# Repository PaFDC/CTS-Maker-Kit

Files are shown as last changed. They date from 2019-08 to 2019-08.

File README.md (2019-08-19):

# Knitted Capacitive Touch Sensor Maker Kit v1.0
This is a repository containing hardware and software source files and documentation for the Knitted Capacitive Touch Sensor (CTS) Maker Kit created by the [Pennsylvania Fabric Discovery Center](https://drexel.edu/functional-fabrics/initiatives/pennsylvania-fabric-discovery-center/).

## How to use this documentation
This documentation is a reference for the construction, application, and maintenance of the CTS hardware and software.

## Project contents
* __hardware__ - [Autodesk EAGLE](https://www.autodesk.com/products/eagle/overview) schematic (.sch) and board (.brd) files used to create the CTS PCB. This folder also contains a bill of materials (BOM) with descriptions of components.
* __firmware__ - Firmware flashed to the [PJRC Teensy 2.0](https://www.pjrc.com/store/teensy_pins.html) microcontroller included on the v1.0 maker kit sensing boards.
* __src__ - Source files for the CTS I2C library used to interface one or more sensor boards to an I2C-enabled Arduino-compatible microcontroller.
* __docs__ - Additional information related to hardware or software documentation.
* __apps__ - Demonstration applications created using the [Processing IDE](https://www.processing.org).

## Getting Started

### What's included in the Maker Kit?
The CTS Maker Kit v1.0 includes the following items:
* (1) Teensy 2.0 microcontroller
* (1) CTS PCB
* (1) Alligator to Molex connector
* (1) Knitted touchpad
* (1) USB type A to mini type B cable
* (1) Insert describing the CTS and containing a link to this GitHub project page.

### Connecting to a PC
The CTS connects to and is powered over USB. The device will mount as a USB serial port (e.g. `COM##` in Microsoft Windows, `/dev/cu.usbmodem#####` in Mac OSX, or `/dev/ttyUSB#` in Ubuntu Linux). You may use the Arduino IDE to monitor serial output by selecting `Tools > Serial Monitor`.

### Connecting to fabric
The alligator clips on the CTS module clip onto the button snaps affixed to the knitted touchpad. The clips can be removed from the PCB via the 3-pin, 0.1" pitch Molex connector. Users may create their own connectors to interface with the PCB using the following Molex [crimps](https://www.taydaelectronics.com/crimp-terminal-connector-3-96mm.html) and [housings](https://www.taydaelectronics.com/housing-connector-2-54mm-3-pins.html).

### Connecting with other CTS modules
The CTS contains breakouts for a 4-pin I2C connector. By default, each sensor board responds as a slave I2C device with address 0x01. The sensor boards can be connected individually to a host microcontroller or daisy-chained to report data from multiple toucpads. __Note:__ Version 1.0 CTS sensor boards must be re-flashed with a different I2C address to respond over the same bus.

The pinout of the I2C breakout is compatible with the [Sparkfun Qwiic I2C adapter](https://www.sparkfun.com/products/14495) with the exception that the voltage output of the sensor is __+5V__ and __not +3.3V__.

## Modifying the hardware
Schematic (.sch) and board layout (.brd) files are located in the __hardware__ folder.

### Extending the firmware
Further information can be found in the [ATmega 32U4 datasheet](http://ww1.microchip.com/downloads/en/devicedoc/atmel-7766-8-bit-avr-atmega16u4-32u4_datasheet.pdf).

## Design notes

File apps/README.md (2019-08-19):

# Knitted Capacitive Touch Sensor Maker Kit Applications

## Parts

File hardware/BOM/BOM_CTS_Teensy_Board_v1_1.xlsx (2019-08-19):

Part | Value | Device | Package | Description | PROD_ID | SF_ID | TP_SIGNAL_NAME | Vendor | Part Number | URL
D1 | RED | LED3MM | LED_3MM | LED (Generic) | DIO-08794 |  |  | Digikey | 732-5013-ND | https://www.digikey.com/product-detail/en/wurth-electronics-inc/151033RS03000/732-5013-ND/4490003
D2 | BLUE | LED3MM | LED_3MM | LED (Generic) | DIO-08794 |  |  | Digikey | 732-5011-ND | https://www.digikey.com/product-detail/en/wurth-electronics-inc/151033BS03000/732-5011-ND/4489997
J1 | 1x3 MOLEX KK-156 RIGHT ANGLE | CONN_03POLAR | MOLEX-1X3 | Multi connection point. Often used as Generic Header-pin footprint for 0.1 inch spaced/style header connections | CONN-08625 | PRT-08096 |  | Tayda Electronics | A-816 | https://www.taydaelectronics.com/wafer-connector-2-54mm-3-pins-right-angle.html
J2 | 1x12 FEMALE | CONN_12 | 1X12 | Multi connection point. Often used as Generic Header-pin footprint for 0.1 inch spaced/style header connections |  |  |  | Digikey | S7045-ND | https://www.digikey.com/product-detail/en/sullins-connector-solutions/PPPC121LFBN-RC/S7045-ND/810184
J3 | 1x12 FEMALE | CONN_12 | 1X12 | Multi connection point. Often used as Generic Header-pin footprint for 0.1 inch spaced/style header connections |  |  |  | Digikey | S7045-ND | https://www.digikey.com/product-detail/en/sullins-connector-solutions/PPPC121LFBN-RC/S7045-ND/810184
J4 | 1x4 MALE | CONN_04 | 1X04 | Multi connection point. Often used as Generic Header-pin footprint for 0.1 inch spaced/style header connections | CONN-09696 |  |  | Digikey | S1112EC-02-ND | https://www.digikey.com/product-detail/en/sullins-connector-solutions/PREC002SBAN-M71RC/S1112EC-02-ND/2774932
J5 | 1x4 MALE | CONN_04 | 1X04 | Multi connection point. Often used as Generic Header-pin footprint for 0.1 inch spaced/style header connections | CONN-09696 |  |  | Digikey | S1112EC-02-ND | https://www.digikey.com/product-detail/en/sullins-connector-solutions/PREC002SBAN-M71RC/S1112EC-02-ND/2774932
R1 | 150 | R-US_0204/7 | 0204/7 | RESISTOR, American symbol |  |  |  | Digikey | S150CACT-ND | https://www.digikey.com/product-detail/en/stackpole-electronics-inc/RNMF14FTC150R/S150CACT-ND/2617812
R2 | 100 | R-US_0204/7 | 0204/7 | RESISTOR, American symbol |  |  |  | Digikey | S100CACT-ND | https://www.digikey.com/products/en?keywords=S100CACT-ND
R3 | 1M | TRIM_US-B90P | SP19L | POTENTIOMETER |  |  |  | Digikey | 3006P-105LF-ND | https://www.digikey.com/product-detail/en/bourns-inc/3006P-1-105LF/3006P-105LF-ND/1087573
R4 | 1M | TRIM_US-B90P | SP19L | POTENTIOMETER |  |  |  | Digikey | 3006P-105LF-ND | https://www.digikey.com/product-detail/en/bourns-inc/3006P-1-105LF/3006P-105LF-ND/1087573
R5 | 4.7K | R-US_0204/7 | 0204/7 | RESISTOR, American symbol |  |  |  | Digikey | S4.7KCACT-ND | https://www.digikey.com/product-detail/en/stackpole-electronics-inc/RNMF14FTC4K70/S4.7KCACT-ND/2617510
R6 | 4.7K | R-US_0204/7 | 0204/7 | RESISTOR, American symbol |  |  |  | Digikey | S4.7KCACT-ND | https://www.digikey.com/product-detail/en/stackpole-electronics-inc/RNMF14FTC4K70/S4.7KCACT-ND/2617510

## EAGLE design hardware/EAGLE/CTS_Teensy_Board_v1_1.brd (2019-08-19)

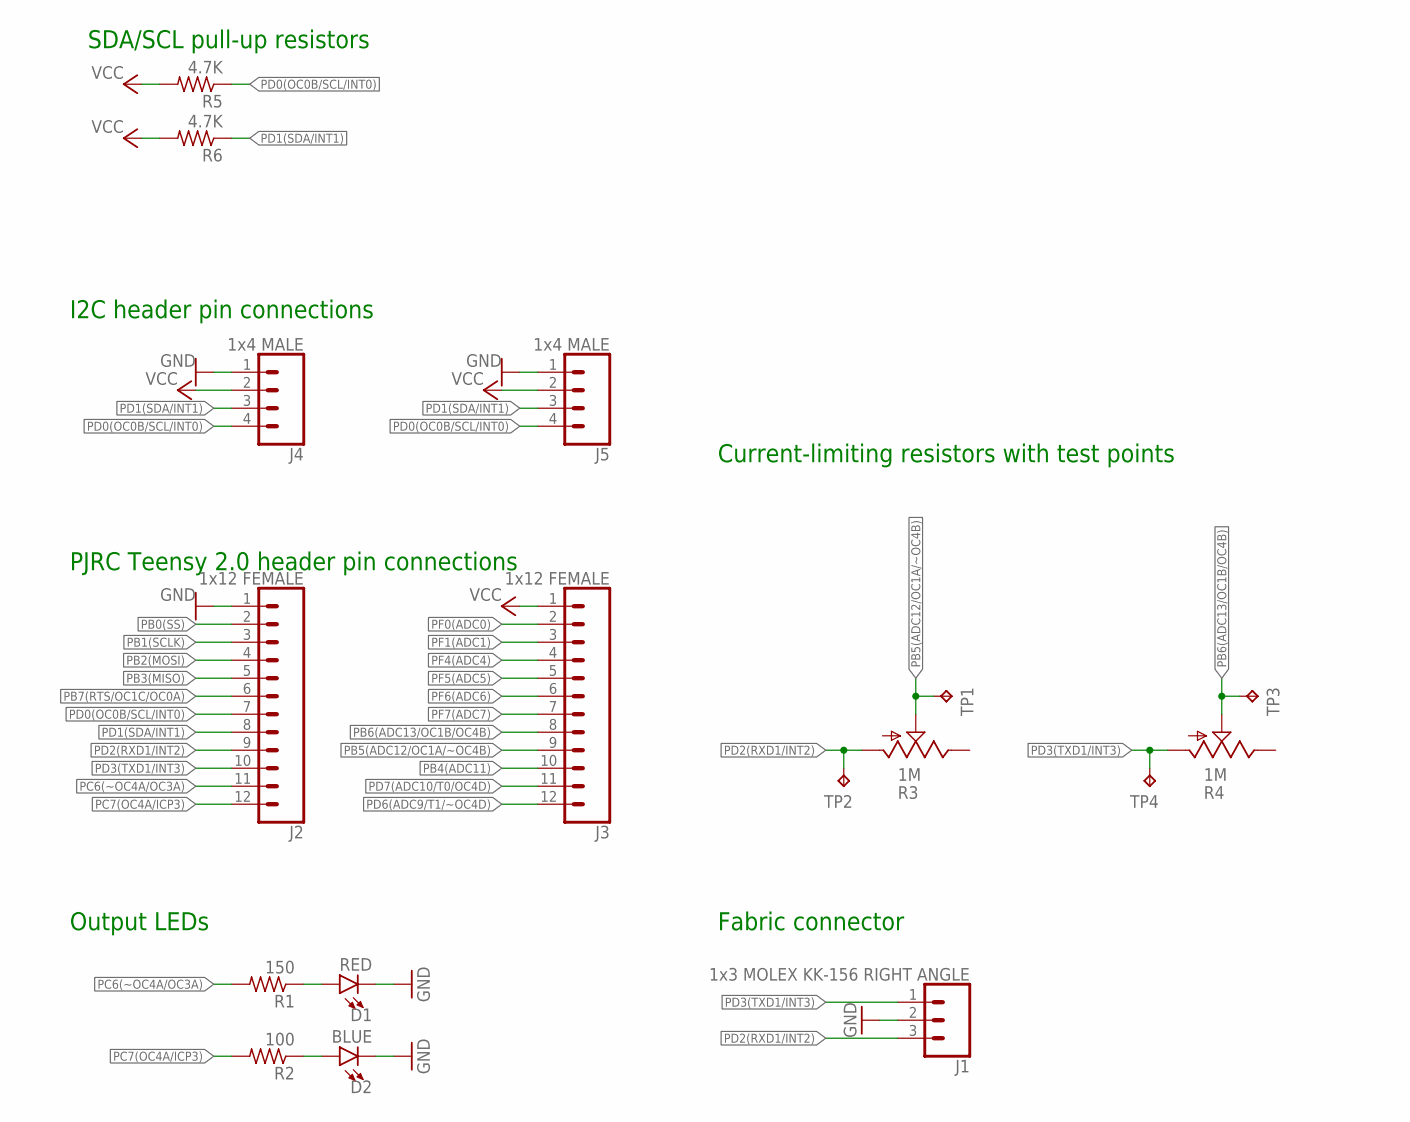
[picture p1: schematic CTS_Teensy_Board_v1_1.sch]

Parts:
D1: RED; LED_3MM
D2: BLUE; LED_3MM
J1: 1x3 MOLEX KK-156 RIGHT ANGLE; MOLEX-1X3
J2, J3: 1x12 FEMALE; 1X12
J4, J5: 1x4 MALE; 1X04
R1: 150; 0204/7
R2: 100; 0204/7
R3, R4: 1M; SP19L
R5, R6: 4.7K; 0204/7
TP1, TP2, TP3, TP4: TPTP18R; TP18R

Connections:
GND: D1.K (C), D2.K (C), J1.2, J2.1, J4.1, J5.1
unnamed: D2.A, R2.1
unnamed: D1.A, R1.1
PB0(SS): J2.2
PB1(SCLK): J2.3
PB2(MOSI): J2.4
PB3(MISO): J2.5
PB4(ADC11): J3.10
PB5(ADC12/OC1A/~OC4B): J3.9, R3.S, TP1.TP
PB6(ADC13/OC1B/OC4B): J3.8, R4.S, TP3.TP
PB7(RTS/OC1C/OC0A): J2.6
PC6(~OC4A/OC3A): J2.11, R1.2
PC7(OC4A/ICP3): J2.12, R2.2
PD0(OC0B/SCL/INT0): J2.7, J4.4, J5.4, R5.1
PD1(SDA/INT1): J2.8, J4.3, J5.3, R6.1
PD2(RXD1/INT2): J1.3, J2.9, R3.A, TP2.TP
PD3(TXD1/INT3): J1.1, J2.10, R4.A, TP4.TP
PD6(ADC9/T1/~OC4D): J3.12
PD7(ADC10/T0/OC4D): J3.11
PF0(ADC0): J3.2
PF1(ADC1): J3.3
PF4(ADC4): J3.4
PF5(ADC5): J3.5
PF6(ADC6): J3.6
PF7(ADC7): J3.7
VCC: J3.1, J4.2, J5.2, R5.2, R6.2

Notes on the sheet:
SDA/SCL pull-up resistors
I2C header pin connections
PJRC Teensy 2.0 header pin connections
Current-limiting resistors with test points
Output LEDs
Fabric connector

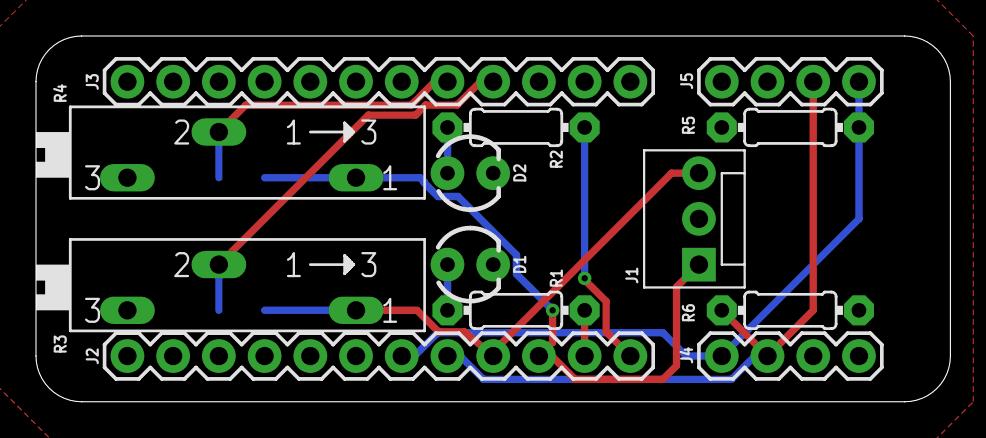
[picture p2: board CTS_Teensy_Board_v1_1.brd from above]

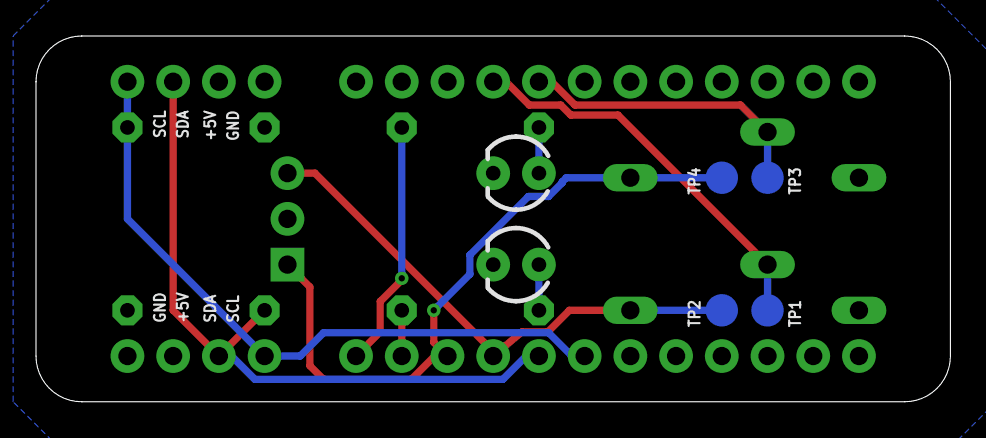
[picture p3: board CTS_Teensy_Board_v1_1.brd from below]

Board: 2 copper layers, 50.8 x 20.3 mm, 17 parts (4 on the bottom side), 12 nets.

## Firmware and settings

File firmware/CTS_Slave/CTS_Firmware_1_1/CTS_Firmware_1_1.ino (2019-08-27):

/*
 *                Teensy 2.0 (Atmega 32U4)
 *                        _______
 *                    ___|       |___
 *               Gnd | o |       | o | Vcc
 * (interior) SS PB0 | o |_______| o | PF0 ADC0       (interior)
 *  PE6     SCLK PB1 | o           o | PF1 ADC1          AREF
 *  AIN0    MOSI PB2 | o           o | PF4 ADC4
 *  INT6    MISO PB3 | o o       o o | PF5 ADC5
 * RTS OC1C OC0A PB7 | o   _____   o | PF6 ADC6
 * OC0B SCL INT0 PD0 | o  |     |  o | PF7 ADC7
 *      SDA INT1 PD1 | o  |     |  o | PB6 ADC13 OC1B OC4B
 *     RXD1 INT2 PD2 | o  |_____|  o | PB5 ADC12 OC1A OC4B
 *     TXD1 INT3 PD3 | o           o | PB4 ADC11
 *    !OC4A OC3A PC6 | o    [   ]  o | PD7 ADC10 T0 OC4D
 *     OC4A ICP3 PC7 | o o o o o o o | PD6 ADC9  T1 !OC4D (LED on PD6)
 *                   |___|_|_|_|_|___|
 *                       | | | | |
 *            CTS XCK1 PD5 | | | PD4 ADC8 ICP1
 *                       Vcc | RST
 *                          GND
 * 
 *                        _______
 *                    ___|       |___
 *               Gnd | o |       | o | Vcc
 * (interior)      0 | o |_______| o | 21 A0        (interior)
 *     24          1 | o           o | 20 A1           AREF
 *                 2 | o           o | 19 A2
 *                 3 | o o       o o | 18 A3
 *        PWM      4 | o   _____   o | 17 A4
 *        PWM INT0 5 | o  |     |  o | 16 A5
 *            INT1 6 | o  |     |  o | 15 A6  PWM
 *         RX INT2 7 | o  |_____|  o | 14 A7  PWM
 *         TX INT3 8 | o           o | 13 A8
 *        PWM      9 | o    [   ]  o | 12 A9  PWM
 *        PWM     10 | o o o o o o o | 11 A10 (LED on 11)
 *                   |___|_|_|_|_|___|
 *                       | | | | |
 *                      23 | | | 22, A11
 *                       Vcc | RST
 *                          GND
 */


/*
 *  Clock Divisor Table
 * 0 | 0 | 0 No clock source
 * 0 | 0 | 1 clk/1
 * 0 | 1 | 0 clk/8
 * 0 | 1 | 1 clk/64
 * 1 | 0 | 0 clk/256
 * 1 | 0 | 1 clk/1024
 * 1 | 1 | 0 
 * 1 | 1 | 1 
 * 
 */


/*
 * Cyclical Buffer Operation
 * 
 * We define a buffer with n elements numbered from 0 to n-1.
 * The buffer elements contain readings taken sequentially.
 * We define an index to track which element is being written/overwritten.
 * We also define a buffer sum that keeps track of the sum of all elements within the buffer.
 * When a reading is taken, the value is placed in an element and the write index is incremented.
 * The removed element is subtracted from the buffer sum and the reading is added.
 * When the index reaches the end of the buffer, the index wraps around to zero.
 * 
 *      buffer, index = x          (n-4) (n-2)
 *  0  1  2  3  4  5  6     x   (n-5) (n-3) (n-1)
 * [#][#][#][#][#][#][#]...[#]...[#][#][#][#][#]
 * 
 * 
 * buffer_sum = buffer_sum + reading
 * buffer_sum = buffer_sum - buffer[x]
 * buffer[x] = reading;
 * 
 * Caveats:
 * 1. Alays add to the buffer sum before subtracting, especially if the buffer sum is an unsigned quantity.
 * 2. Avoid adding and subtracting quantities in the same line to avoid order of operations conflicts and variable wrap-around.
 * 
 */


/*
 * Exponential Moving Average
 * 
 * S_t = Y_1,               t = 1
 *       a*Y_t + (1-a)*S_t, t > 1
 * 
 * a ~= 0: Favor prior readings over newer readings
 * a ~= 1: Favor newer readings over prior readings
 * 
 */

#include <Wire.h>
#include <EEPROM.h>
#include "cts_utility.h"

// Length of the cyclical buffer used for the low-pass filter reading
// Higher values produce a "smoother" output but slow responsiveness to changes in touch
#define CYC_BUFF_LEN (128)

#define MHz_TO_MICROS (16)    // Scaling clock ticks in MHz to microseconds
#define DT_TO_DELAY   (1000)  // 1000 Microseconds per 1 Hz
#define SAMPLE_RATE   (100)   // Hz, approximate
#define CUTOFF        (5)     // Hz

// A (red) and B (blue) electrode LED pins
#define REDLED (10)           // Pin 10
#define BLUELED (9)           // Pin 9

#define CYC_BASELINE_BUFF_LEN (128) // 


#define EEPROM_I2C_ADDRESS (0)


// I2C slave address
uint8_t address = 1;

volatile uint8_t state = 0;     // State of timer interrupt (intital condition)

uint8_t idx = 0;                // Index of the cyclical buffer
uint32_t buffer_overflow = 0;   // Number of times the cyclical buffer has overflowed

// Wait "n" number of milliseconds to begin analyzing readings
// This gives the buffer time to flush dummy (zero) readings and populate with real data
uint16_t start_after = 2000;

uint16_t cyc_buffer[CYC_BUFF_LEN][2] = { { 0, }, { 0, } }; // Definition of the cyclical buffer
uint32_t cyc_buffer_sum[2] = { 0, }; // Definition of the buffer sum

uint16_t tau_A = 0; // Signal A rise time
uint16_t tau_B = 0; // Signal B rise time

float smoothreadings[2][2] = { { 0, 0 }, { 0, 0 } };
float highpass[2][2] = { { 0, 0 }, { 0, 0 } };

// Filter gains
float dt = 1.0/SAMPLE_RATE;     // Time change
float RC = 1.0/(2.0*PI*CUTOFF); // "RC" constant of system
float alpha = RC/(RC + dt);     // High pass filter gain

// A and B electrode signal reading
float sigA = 0.0;
float sigB = 0.0;

float sigAScaled = 1.0;
float sigBScaled = 1.0;

uint8_t ledA = 0;
uint8_t ledB = 0;

float minReading[] = { 1000.0, 1000.0 };
float maxReading[] = { 0.0, 0.0 };

uint8_t minLEDBrightness[] = { 0, 0 };
uint8_t maxLEDBrightness[] = { 63, 63 };

uint32_t delay_time = (uint32_t)(DT_TO_DELAY*dt);

// Empirically observed base rise time
float baseA = 18.0;
float baseB = 18.0;

float th = 0.30;

uint8_t istouched  = 0;

String delim = " ";

float pressThreshold = 10.0;
float releaseThreshold = -2.5;

float valuemin = -1.0;
float valuemax = 0.9;
float outmin = 0.0;
float outmax = 25.0;

int channel = 1;
uint8_t note = 48;
uint8_t velocity = 99;

float baseline[CYC_BASELINE_BUFF_LEN][2] = { { 0.0 }, { 0.0 } };
float baseline_sum[2] = { 0, 0 };
uint8_t baseline_idx = 0;

struct CTSDataStruct{
  float raw[2];
  float highpass[2];
  float x;
  float pressure;
} dataStruct;

void setup() {
  // Start the serial port
  Serial.begin(115200);

  // Start the I2C port with the specified address
  Wire.begin(address);

  // Set the I2C request for data callback function
  Wire.onRequest(wireCallback);

  // Enable the built-in LED
  pinMode(LED_BUILTIN, OUTPUT);

  // Set the PWM-enabled LED pins
  pinMode(REDLED, ledA);
  pinMode(BLUELED, ledB);

  // Initialize the CTS pins
  initCTS();

  // Wait for serial connection
  //while (!Serial);
  delay(start_after);

  // Turn on the built-in LED
  digitalWrite(LED_BUILTIN, HIGH);
}

/*
 * TODO:
 * self-calibration
 * 
 * The sensor subtracts an offset reading from the A and B signals when there is no touch.
 * The sensor is allowed to adjust the baseline offset when
 * 
 * Map the exponential filter alpha between 0 and 1
 * 
 */

void loop() {
  // Delay the loop
  delay(delay_time);
  
  // Get the windowed moving average
  sigA = (float)cyc_buffer_sum[0]/(MHz_TO_MICROS*CYC_BUFF_LEN);
  sigB = (float)cyc_buffer_sum[1]/(MHz_TO_MICROS*CYC_BUFF_LEN);
  
  // Set the average to the smoothing window
  smoothreadings[0][0] = sigA;
  smoothreadings[1][0] = sigB;
  
  // Find the highpass filter value
  highpass[0][0] = alpha*(highpass[0][1] + smoothreadings[0][0] - smoothreadings[0][1]);
  highpass[1][0] = alpha*(highpass[1][1] + smoothreadings[1][0] - smoothreadings[1][1]);

  
  if ((abs(highpass[0][0]) > th || abs(highpass[1][0]) > th) && !istouched) {
    Serial.println("Here");
    istouched = true;  // Raise touched flag
    digitalWrite(LED_BUILTIN, LOW);
    baseA = baseline_sum[0]/CYC_BASELINE_BUFF_LEN;
    baseB = baseline_sum[1]/CYC_BASELINE_BUFF_LEN;
  } else if (!istouched) {
    baseline_sum[0] += sigA;
    baseline_sum[1] += sigB;
    baseline_sum[0] -= baseline[baseline_idx][0];
    baseline_sum[1] -= baseline[baseline_idx][1];
    baseline[baseline_idx][0] = sigA;
    baseline[baseline_idx][1] = sigB;
    digitalWrite(LED_BUILTIN, LOW);
    baseline_idx++;
    baseline_idx = (baseline_idx >= CYC_BASELINE_BUFF_LEN)? 0 : baseline_idx;
  } else if ((abs(highpass[0][0]) < th || abs(highpass[1][0]) < th) && istouched) {
    istouched = false;  // Lower touched flag
    digitalWrite(LED_BUILTIN, LOW);
  }
  
  // 
  sigAScaled = sigA - baseA;
  sigBScaled = sigB - baseB;
  
  // 
  sigAScaled = (sigAScaled < 1.0)? 1.0 : sigAScaled;
  sigBScaled = (sigBScaled < 1.0)? 1.0 : sigBScaled;
  
  // 
  ledA = (uint8_t)map(sigAScaled, 1.0, 60.0, 0, 127);
  ledB = (uint8_t)map(sigBScaled, 1.0, 60.0, 0, 127);
  
  //updateReadingLimits();
  
  // 
  highpass[0][1] = highpass[0][0];
  highpass[1][1] = highpass[1][0];
  smoothreadings[0][1] = smoothreadings[0][0];
  smoothreadings[1][1] = smoothreadings[1][0];
  
  // 
  analogWrite(REDLED, ledA);
  analogWrite(BLUELED, ledB);
  

  dataStruct.raw[0] = sigA;
  dataStruct.raw[1] = sigB;
  dataStruct.highpass[0] = highpass[0][0];
  dataStruct.highpass[1] = highpass[1][0];
  dataStruct.x = log(sigAScaled) - log(sigBScaled);
  dataStruct.pressure = (sigAScaled + sigBScaled)/2.0 - 1.0;

  Serial.print(dataStruct.raw[0]);
  Serial.print(delim);
  Serial.print(dataStruct.raw[1]);
  Serial.print(delim);
  Serial.print(dataStruct.highpass[0]);
  Serial.print(delim);
  Serial.print(dataStruct.highpass[1]);
  Serial.print(delim);
  Serial.print(dataStruct.x);
  Serial.print(delim);
  Serial.println(dataStruct.pressure);
  
  delay(10);
}

void wireCallback() {
  Wire.write((uint8_t *)&dataStruct, 24);
}




void updateReadingLimits() {    
  //ledA = map(sigA, minReading[0], maxReading[0], 0.0, 1.0);
  //if ledA < 0
  //ledB = map(sigB, minReading[1], maxReading[1], 0.0, 1.0);
}

/*
 * External Interrupt INT0 (Digital pin 5)
 */
ISR(INT2_vect) {
  tau_A = TCNT1;        // Record the signal A rise time
  PORTD |= (1 << DDD5); // Fire the interrupt trigger
}

/*
 * External Interrupt INT1 (Digital pin 6)
 */
ISR(INT3_vect) {
  tau_B = TCNT1;        // Record the signal B rise time
  PORTD |= (1 << DDD6); // Fire the interrupt trigger
}

/*
 * TIMER1 Compare channel A vector
 */
ISR(TIMER1_COMPA_vect) {
  // Invert digital pins 9 and 10
  PORTB ^= (1 << DDB6) | (1 << DDB5);

  // Put the tau_A and tau_B readings into the cyclical buffer (add before subtracting)
  cyc_buffer_sum[0] += tau_A;
  cyc_buffer_sum[0] -= cyc_buffer[idx][0];
  cyc_buffer_sum[1] += tau_B;
  cyc_buffer_sum[1] -= cyc_buffer[idx][1];
  cyc_buffer[idx][0] = tau_A;
  cyc_buffer[idx][1] = tau_B;

  idx++; // Increment the buffer index and reset to zero if it reaches the end
  if (idx >= CYC_BUFF_LEN) {
    idx = 0;
    buffer_overflow++;
  }
}

/*
 * TIMER1 Compare channel B vector
 */
ISR(TIMER1_COMPB_vect) {
  // Do nothing
}

uint8_t readAddress() {
  return EEPROM.read(EEPROM_I2C_ADDRESS);
}

/*Serial.print(dataStruct.raw[0]);
  Serial.print(delim);
  Serial.print(dataStruct.raw[1]);
  Serial.print(delim);
  Serial.print(dataStruct.highpass[0]);
  Serial.print(delim);
  Serial.print(dataStruct.highpass[1]);
  Serial.print(delim);
  Serial.print(dataStruct.x);
  Serial.print(delim);
  Serial.print(dataStruct.pressure);
  Serial.print(delim);
  Serial.print(baseline_sum[0]);
  Serial.print(delim);
  Serial.print(baseline_sum[1]);
  Serial.print(delim);
  */

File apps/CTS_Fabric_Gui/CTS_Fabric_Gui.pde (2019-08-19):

import processing.serial.*;
import javax.swing.*; //for serial port prompt

boolean setup = true;
// toggle prompt for choosing serial port

int lf = 10;  // linefeed in ASCII
String myString = null; //raw serial data
float[] data = new float[2]; //serial data split in 2 numbers
Serial myPort;  // serial port

float margin, headerHeight, rectsHeight, barsHeight, graphHeight;

int rgb[][] = {
  { 200, 55, 110 }, //0: left axis
  {  20, 85, 140 }
}; //1: right axis
color bg = color(242);
color light = color(245, 195, 215); //light pressure
color dark = color(200, 55, 110); //heavy pressure 
color header = color(255); //header text
color stroke = color(190);
color subtitleBG = color(20, 85, 140);
color subtitle = color(255);
color rectsFill = color(230, 245, 255);

int numRects = 16; // number of sensor rectangles
int maxRects = 40; // max number of sensor rectangles
int rectInc = 2; // sensitivity increment
float[][] rects = new float[maxRects][4]; // coordinates for each rect


float[][] readings = new float[4][2000]; // all readings
// 0: left readings
// 1: right readings
// 2: raw n value
// 3: n-normalized

float[][] plot = new float[2][2000]; // scaled left-right readings

float time[] = new float[2000];
float startingLine = 0.9; // how far across the screen the current data point is drawn

volatile int vIdx = 1300;
int idx = 1300;

volatile boolean vRunning = true;
boolean running = true;
boolean console = false;
boolean mousePause = false;
boolean mouseReset = false;
boolean mouseConsole = false;

float sensitivity[][] = { { 10.0, 40.0 }, { 20.0, 40.0 }, { 15.0, 20.0 }, {10.0, 15.0 } };
int sidx = 0; // Sensitivity index
float pLower = sensitivity[sidx][0]; // Default to first lower pressure sensitivity
float pUpper = sensitivity[sidx][1]; // Default to first upper pressure sensitivity

int inc = 30; // arrow increment

PImage logo, pause, play, reset, settings;
PFont font, fontBold;
int headFontSize = 28; //header title
int subFontSize = 14; //

float mainWidth, frameWidth;

//also adjust default values in reset() function
float maxLeft = 45.0;
float maxRight = 45.0;
float max = 45.0;

String delim = " ";

void setup() {

  //size(displayWidth, displayHeight);
  size(850, 650);
  surface.setResizable(true); // allow the canvas to be resized
  pixelDensity(displayDensity()); // renders hq if retina display

  background(bg);
  logo = loadImage("logo.png");
  pause = loadImage("pause.png");
  play = loadImage("play.png");
  reset = loadImage("reset.png");
  settings = loadImage("list.png");

  font = loadFont("Helvetica-16.vlw");
  fontBold = loadFont("Helvetica-Bold-30.vlw");


  println((Object)Serial.list()); //print available serial ports to console


  if (!setup) {
    //if setup is turned off, default to using this port
    myPort = new Serial(this, "/dev/cu.usbmodem1421", 115200);

    myPort.clear(); // throw out the first reading, in case we started reading in the middle of a string from the sender
    myString = myPort.readStringUntil(lf);
    myString = null;
    xScale();
    yScale();
  } else
  {
    try {
      Object selection;
      String port = "";
      int i = Serial.list().length;

      if (i > 0) {
        //if there are multiple ports available, ask which one to use
        selection = JOptionPane.showInputDialog(frame, "Select serial port number to use:\n", "Setup", JOptionPane.PLAIN_MESSAGE, null, Serial.list(), Serial.list()[0]);
        if (selection == null) exit();

        println(selection);
        port = selection.toString();
        println(port);
        myPort = new Serial(this, port, 115200);

        myPort.clear(); // throw out the first reading, in case we started reading in the middle of a string from the sender
        myString = myPort.readStringUntil(lf);
        myString = null;
        xScale();
        yScale();
        //println(time);
      } else {
        JOptionPane.showMessageDialog(frame, "Device is not connected to the PC");
        exit();
      }
    }
    catch (Exception e)
    { //Print the type of error
      JOptionPane.showMessageDialog(frame, "COM port is not available (may\nbe in use by another program)");
      println("Error:", e);
      exit();
    }
  }//end if(showSetup)
}//end setup



void draw() {
  //since window is resizable, the height of each element is based on
  //a fraction of the height of the window (using the 'margin' as a base unit).
  margin = height / 26.0;
  headerHeight = margin * 4.0;
  rectsHeight = margin * 5.0;
  barsHeight = margin * 5.0;
  graphHeight = margin * 5.0;

  //frameWidth is the width of the window containing the main program elements
  //when the console is on, the program takes up less of the window so the console can show on the side
  if (console) frameWidth = width * 0.7;
  else frameWidth = width;
  mainWidth = frameWidth - margin * 2.0;


  while (myPort.available() > 0) {
    myString = myPort.readStringUntil(lf);
  }
  if (myString != null) {
    data = float(split(myString, delim)); //split raw data into 2 numbers
    println(data);

    if (data[0] > maxLeft) maxLeft = data[0];
    if (data[1] > maxRight) maxRight = data[1];
    if (maxLeft > maxRight) max = maxLeft;
    else max = maxRight;
    //update max reading values as you go

    if (running)
    {
      readings[0][readings[0].length-1] = (-1) * data[0];
      readings[1][readings[1].length-1] = (-1) * data[1];

      // Map the element so it fits in our graph
      plot[0][plot[0].length-1] = map(readings[0][readings[0].length-1], 0, max, 0, graphHeight);
      plot[1][plot[1].length-1] = map(readings[1][readings[1].length-1], 0, max, 0, graphHeight);


      for (int j = 0; j < 2; j++)
      {
        for (int i = idx; i < time.length - 1; i++)
        {
          readings[j][i] = readings[j][i + 1]; // Shift the readings to the left so can put the newest reading in
          plot[j][i] = plot[j][i + 1];
        }
      }
    }//end if(running)
  }//end if(myString != null)

  background(bg);

  if (width < 540 || height < 400) {  
    headFontSize = 14; 
    subFontSize = 10;
  } else { 
    headFontSize = 28; 
    subFontSize = 14;
  }

  //draw header
  noStroke();
  fill(header);
  rect(0, 0, width, headerHeight);
  textFont(fontBold, headFontSize);
  fill(10, 40, 75);
  text("Fabric Touch Sensor Visualizer", margin, headerHeight/2.0 + (headFontSize/2.0));
  fill(stroke);
  rect(0, headerHeight, width, 2);
  if (width > 650 && height > 400) image(logo, width-200-margin, headerHeight/2.0 - 28, 200, 56);

  touchLocation();
  sensitivityBars();
  sensitivityGraph();
  if (console) console();
  drawButtons();
}//end draw
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

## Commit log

2019-08-19 Initial project file commit
    Added apps, hardware, firmware, and library.
    [BOM_CTS_Teensy_Board_v1_1.xlsx, CTS_Teensy_Board_v1_1.brd, CTS_Teensy_Board_v1_1.sch]
2019-08-27 Added self-calibration firmware v1.1

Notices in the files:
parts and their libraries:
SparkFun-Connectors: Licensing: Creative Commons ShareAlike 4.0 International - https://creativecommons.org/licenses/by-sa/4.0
